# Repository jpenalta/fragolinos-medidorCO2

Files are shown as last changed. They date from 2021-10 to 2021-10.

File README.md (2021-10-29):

# fragolinos-medidorCO2
Medidor de CO2 para a aula realizado polo Club de Ciencias do IES Antonio Fraguas

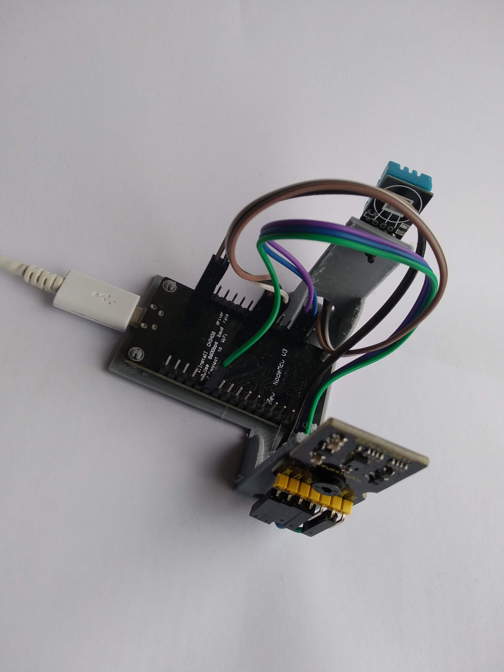
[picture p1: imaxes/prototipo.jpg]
prototipo


## Descrición do proxecto
Este dispositivo foi deseñado para ser montado polos alumnos do Club de Ciencias. Os obxectivos era por unha parte introducir aos alumnos no mundo IOT, e por outro dispoñer dun medidor da calidade do aire das aulas.

O sensor [CSS811](https://www.sciosense.com/products/environmental-sensors/ccs811-gas-sensor-solution/) utilizado non mide CO2, se non [VOC](https://es.wikipedia.org/wiki/Compuestos_org%C3%A1nicos_vol%C3%A1tiles), e realiza unha estimación do CO2 a partir desas medicións. Non é realmente o sensor ideal, xa que resulta moi sensible a compostos químicos, como productos de limpeza ou colonias, pero a relación calidade-precio era un requisito. Un sensor CCS811 pódese atopar entre 10 e 15 Euros, mentras que un sensor de maís calidade, que mide CO2 directamente, non baixa dos 30 Euros.

O precio do sensor de humidade e temperatura [DHT11](https://learn.adafruit.com/dht) é moi barato (2 Euros), por eso se aproveitou para engadilo, dando información adicional do estado da aula.

En total montáronse 20 dispositivos, que foron instalados en distintas aulas de 1º, 2º, 3º e 4º da ESO. En cada aula había un cartel cun código QR que permitía o acceso á páxina de [thingspeak.com](https://thingspeak.com/)  cos datos e gráficas dos parámetros recollidos.

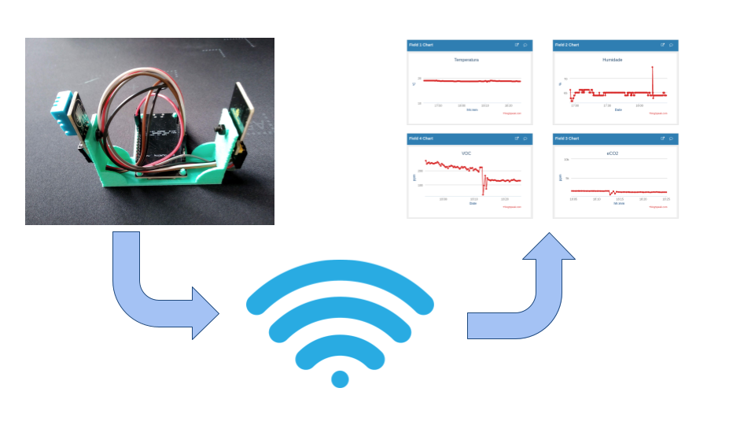
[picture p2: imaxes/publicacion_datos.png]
publicación de los datos


O coste de cada dispositivo foi aproximadamente duns 22 euros. Na carpeta docs existe unha folla de cálculo coa estimación dos costes de cada compoñente.
                                                       
## Carpetas
* **doc**: Presentacións realizadas para explicar aos alumnos o proxecto e como manuais de montaxe.
* **src**: Código arduino
* **soporteESP8266**: ficheiros para a impresión 3D do soporte da placa e os sensores.
* **imaxes**: Diversas imaxes do sensor e os seus compoñentes.

##

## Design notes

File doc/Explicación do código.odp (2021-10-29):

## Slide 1

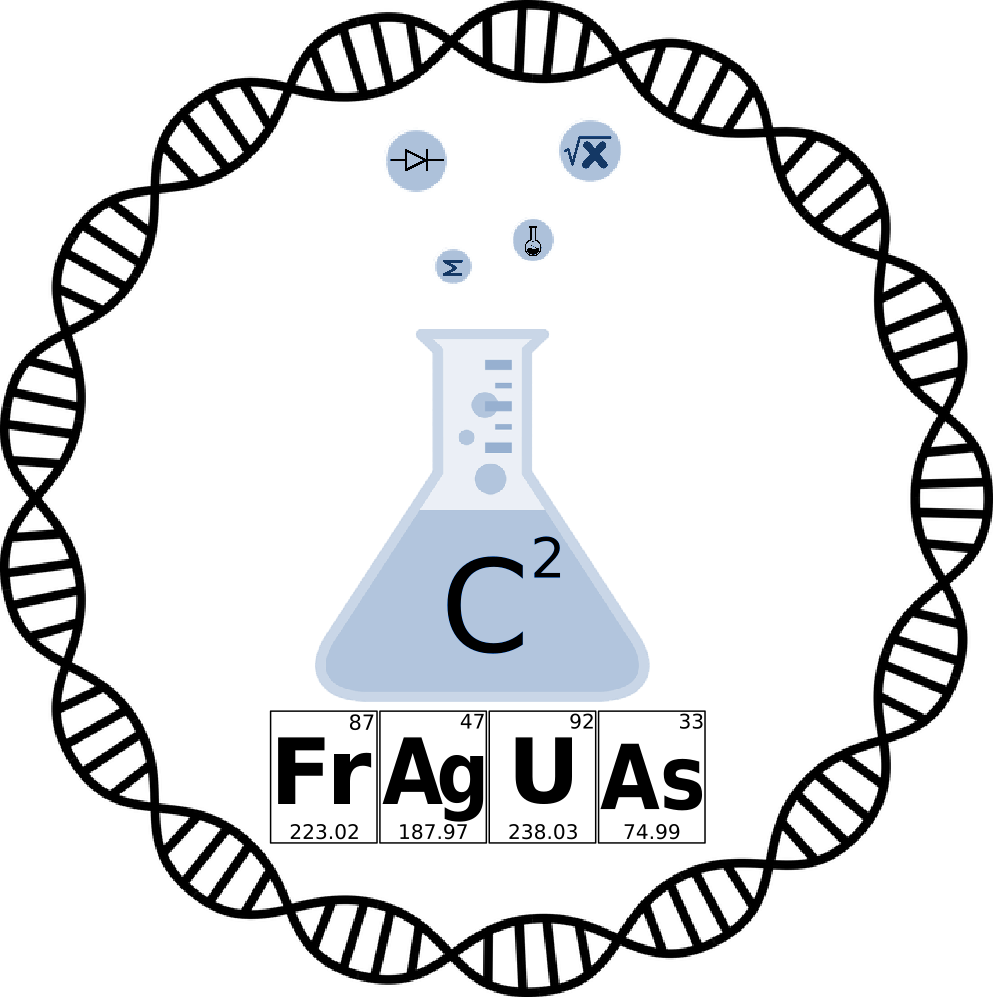
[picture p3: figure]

Explicación do código

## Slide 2

#include "secrets.h"

#include "ESP8266WiFi.h"

#include "ThingSpeak.h"

#include "DHT.h"

#include "Adafruit_CCS811.h"

Esta parte encárgase de cargar as librerías que nos van facilitar crear o programa.

As librerías son pequenos programas que fixo outra xente e que fan parte do traballo por nos. Así o noso programa é máis pequeno e maís fácil de entender

- ESP8266WiFi.h Permite conectarse a unha rede wifi.
- ThingSpeak.h Permite enviar os datos ao servidor de internet.
- DHT.h Permite leer os datos do sensor de temperatura.
- Adafrouit_CCS811.h Permite leer os datos do sensor de CO2.

Configuración 1

Cargar librerías

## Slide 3

// Configuración conexión a ThingSpeak

unsigned long myChannelNumber = SECRET_CH_ID;

const char * myWriteAPIKey = SECRET_WRITE_APIKEY;

const char * myReadAPIKey = SECRET_READ_APIKEY;

// Configuración conexión a WIFI

char ssid[] = SECRET_SSID;

char pass[] = SECRET_PASS;

// Pin donde ler os datos do sensor de DHT11

uint8_t DHTPin = DHT_PIN;

// Variables onde gardar os datos

float temperatura;

float humidade;

float eCO2;

float VOC;

// Liña base para o arrancar o sensor CCS811

uint16_t CCS811_baseline;

Adafruit_CCS811 ccs;

DHT dht(DHT_PIN, DHTTYPE);

WiFiClient client;

Esta parte encargase de definir e dar valores a variables que despois imos necesitar.

Damos valores por exemplo a wifi á que nos imos conectar e a súa contrasinal. E o pin onde hai que conectar o sensor de humidade.

Definimos variables onde imos gardar os datos de temperatura, humidade, etc...

Configuración 2

Definir variables

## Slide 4

Empezamos o bloque setup() que se executa só unha vez, cada vez que enchufamos a placa. Este bloque vale para arrancar todo o que imos necesitar despois.

O primeiro que facemos e conectarnos á WIFI.

Esta liña: while (WiFi.status() != WL_CONNECTED) {

Vai facer que o intente ata que consiga conectarse.

Se o consegue imprime polo porto serie ( se a placa está enchufada a un ordenador) a IP.

void setup() {

Serial.begin(9600);

delay(100);

// Conectado coa WIFI

WiFi.mode(WIFI_STA);

if (WiFi.status() != WL_CONNECTED) {

Serial.print("Intentando conectar a rede WIFI: ");

Serial.println(SECRET_SSID);

while (WiFi.status() != WL_CONNECTED) {

WiFi.begin(ssid, pass);

Serial.print(".");

delay(5000);

}

Serial.println("\nConnected.");

}

// Mostrar la dirección ESP IP en el Monitor Serie

Serial.println(WiFi.localIP());

Preparación 1

Conexión a wifi

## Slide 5

Nesta parte configuramos e probamos a conexión con ThinkSpeak, a páxina onde imos gardar os datos do nos sensor

// Iniciamos a conexión coa páxina onde enviar os datos

ThingSpeak.begin(client);

int statusCode = 999;

boolean existsBaseline = false ;

Serial.print("Intentando recuperar baseline para CCS811:");

for( int i=0; i<4; i++){

CCS811_baseline = ThingSpeak.readLongField(myChannelNumber, 5, myReadAPIKey);

statusCode = ThingSpeak.getLastReadStatus();

delay(5000);

Serial.print(i);

if(statusCode == 200){

existsBaseline = true;

break;

}

}

Serial.println(CCS811_baseline);

Preparación 2

Conexión a ThinkSpeak

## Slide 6

Nesta parte onde imos preparar o sensor de temperatura e de CO2.

//Iniciar sensor DHT11

Serial.println("Iniciando sensor temperatura");

pinMode(DHT_PIN, INPUT);

dht.begin();

//Iniciar sensor CSS811

Serial.println("Iniciando sensor CO2");

if(!ccs.begin()){

Serial.println("Error al iniciar el sensor de CO2.");

while(1);

}

ccs.setDriveMode(CCS811_DRIVE_MODE_10SEC);

if(existsBaseline){

ccs.setBaseline(CCS811_baseline);

}

// Esperamos a que todo esté listo.

delay(DELAY);

}

Preparación 3

Configuración sensores

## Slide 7

Leemos os datos dos sensores e os gardamos nas variables que xa tiñamos preparadas.

*

* Aquí leemos os valores dos sensores é o enviamos ao servidor.

*

*/

void loop() {

// Leemos a temperatura e humidade do sensor DHT11

temperatura = dht.readTemperature();

humidade = dht.readHumidity();

// Leemos o VOC e eCO2 do sensor CCS811

if(ccs.available()){

if(!ccs.readData()){

eCO2 = ccs.geteCO2();

VOC = ccs.getTVOC();

CCS811_baseline = ccs.getBaseline ();

ccs.setEnvironmentalData(temperatura, humidade);

}

}

Todo o rato...

Leemos os sensores

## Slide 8

Enviamos os datos que leimos dos sensores á páxina de ThingSpeak.

Tamén os enviamos ao USB (por serie) para poder comprobar dende un ordenador que funciona ben.

// Enviamos os datos ao servidor

ThingSpeak.setField(1,temperatura);

ThingSpeak.setField(2,humidade);

ThingSpeak.setField(3,eCO2);

ThingSpeak.setField(4,VOC);

ThingSpeak.setField(5,CCS811_baseline);

int httpCode = ThingSpeak.writeFields(myChannelNumber, myWriteAPIKey);

if (httpCode == 200) {

Serial.println("Enviados los datos correctamente.");

digitalWrite(LEDPin, LOW);

delay(500);

digitalWrite(LEDPin, HIGH);

}

else {

Serial.println("Problema al enviar los datos. HTTP error code " + String(httpCode));

}

Todo o rato...

Enviamos os datos á web

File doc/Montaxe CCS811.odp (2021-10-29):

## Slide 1

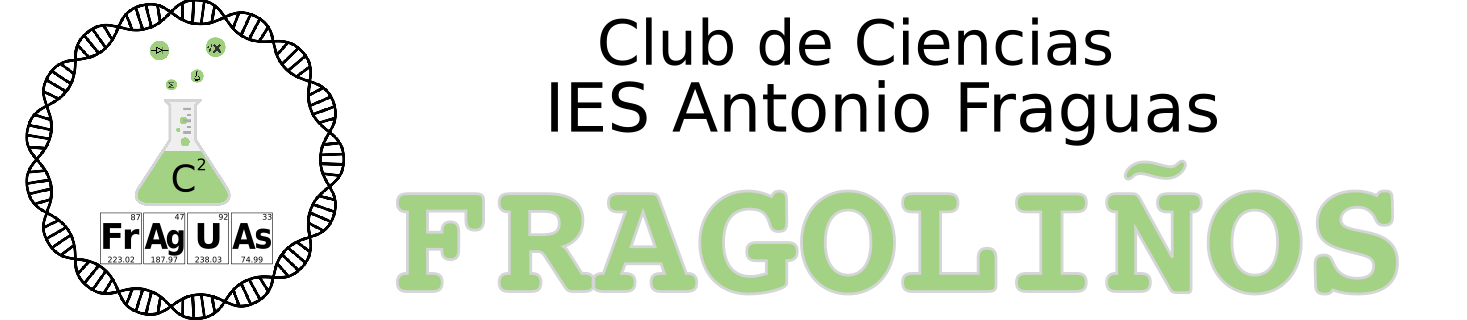
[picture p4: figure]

Montaxe sensor CO2

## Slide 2

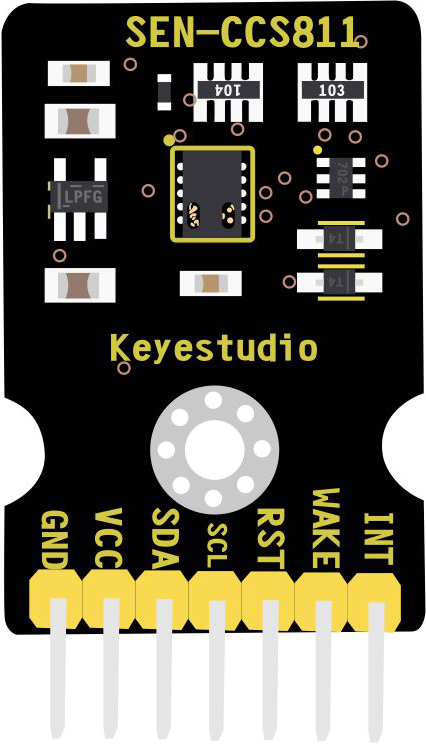
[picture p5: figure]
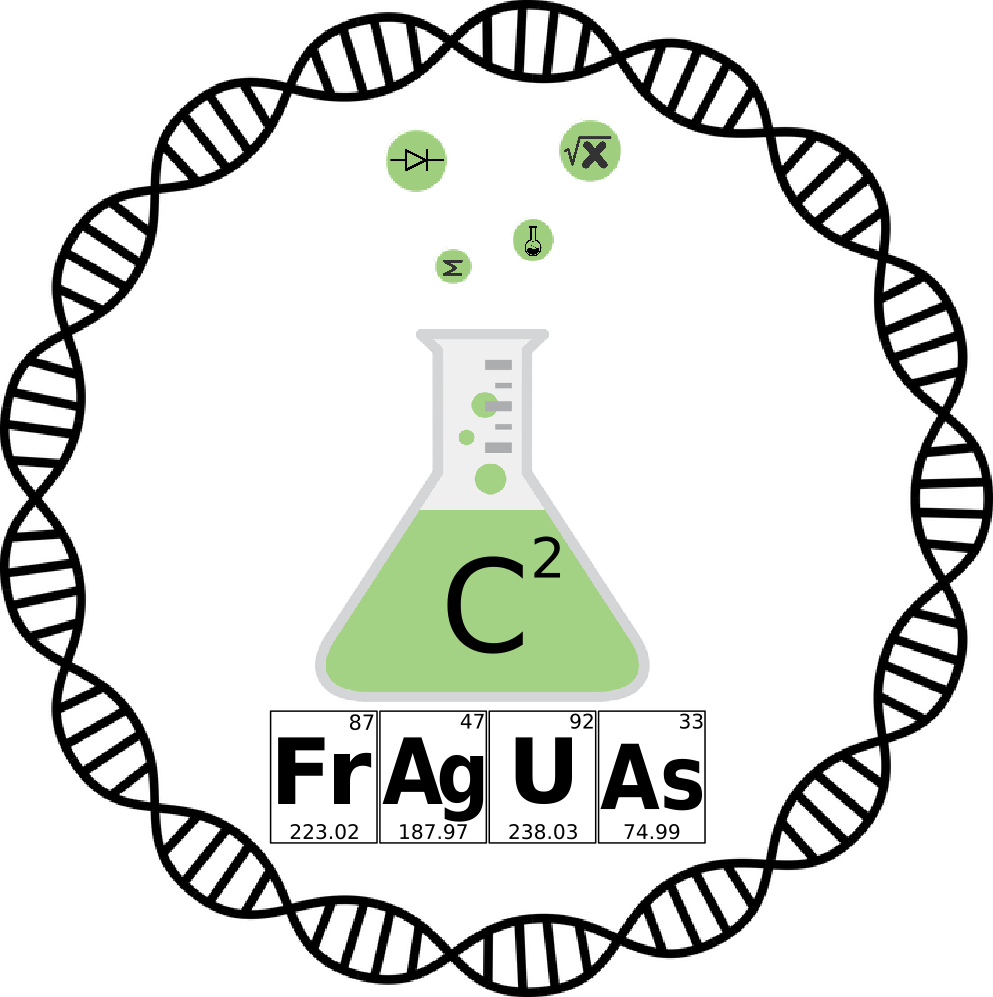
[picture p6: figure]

Modelo: CCS811

- Sensor de particulas VOC (Compuestos Organicos Volatiles)
- Estima particulas CO2 a partir das particulas VOC

CCS811 | Descripción
GND | Masa. Polo -
VCC | Voltaxe. Polo +
SDA | Datos para a transmisión das medicións
SCL | Datos para a transmisión das medicións
RST | Resetea o sensor
WAKE | Encende o sensor
INT | Indica cando o sensor ten unha nova medición.

Montaxe sensor CO2

Características e pines

CO2 1 de 2

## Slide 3

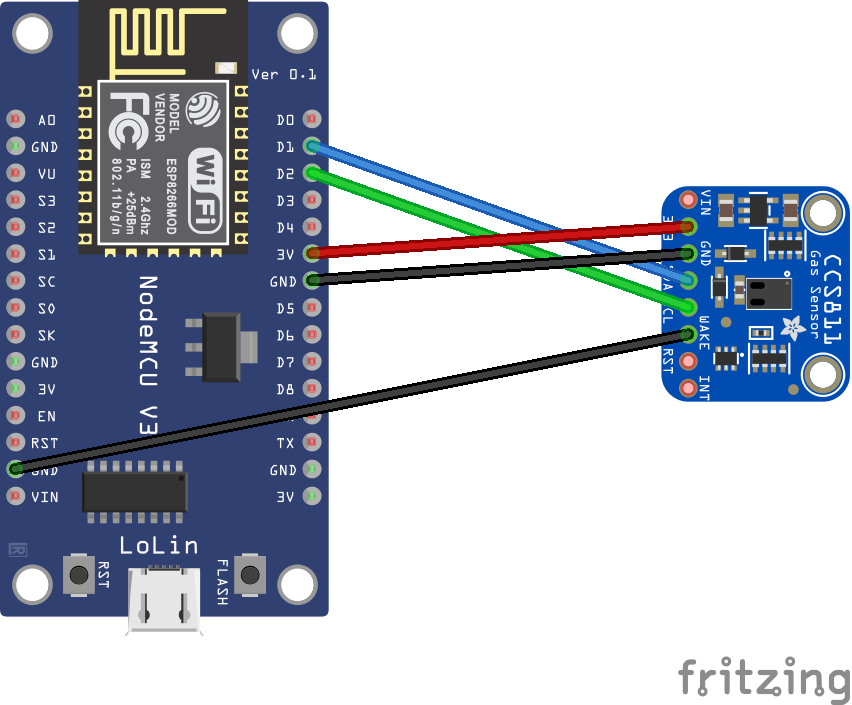
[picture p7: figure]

O gráfico corresponde a outro módelo. Fixarxe na táboa onde ten que ir cada cable na placa. Ter coidado sobre todo co VCC e o GND.

Montaxe sensor CO2

Como se enchufa á placa

CCS811 | PLACA
GND | GND
VCC | 3V
SDA | D1
SCL | D2
RST | -
WAKE | GND
INT | -

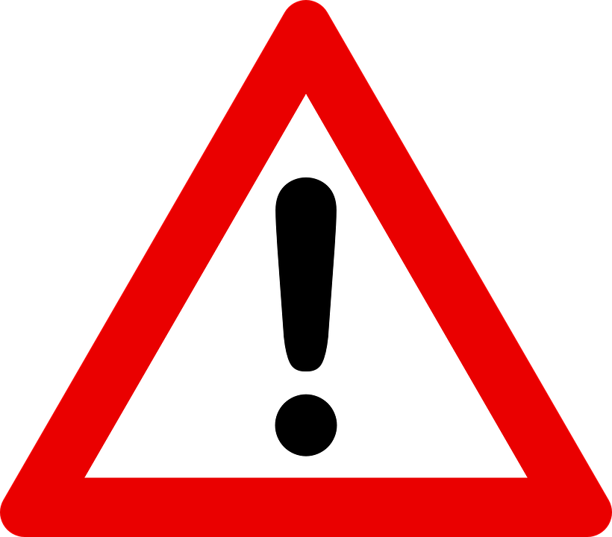
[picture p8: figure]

CO2 2 de 2

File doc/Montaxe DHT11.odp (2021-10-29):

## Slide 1


Montaxe sensor Temperatura e humidade

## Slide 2

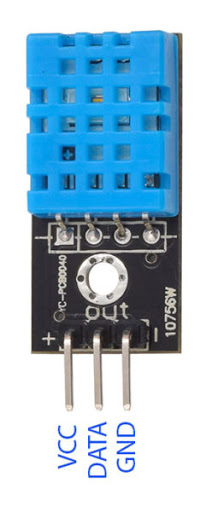
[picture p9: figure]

Modelo: DHT11

- Proporciona información da temperatura e da humidade no ambiente.
- A temperatura en ºC a humidade en %

DHT11 | Descrición
+ | Alimentación. Polo +
OUT | Datos
- | Masa. Polo -

Montaxe sensor Temp. e Hum.

Características e pines

DHT11 1 de 2

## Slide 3

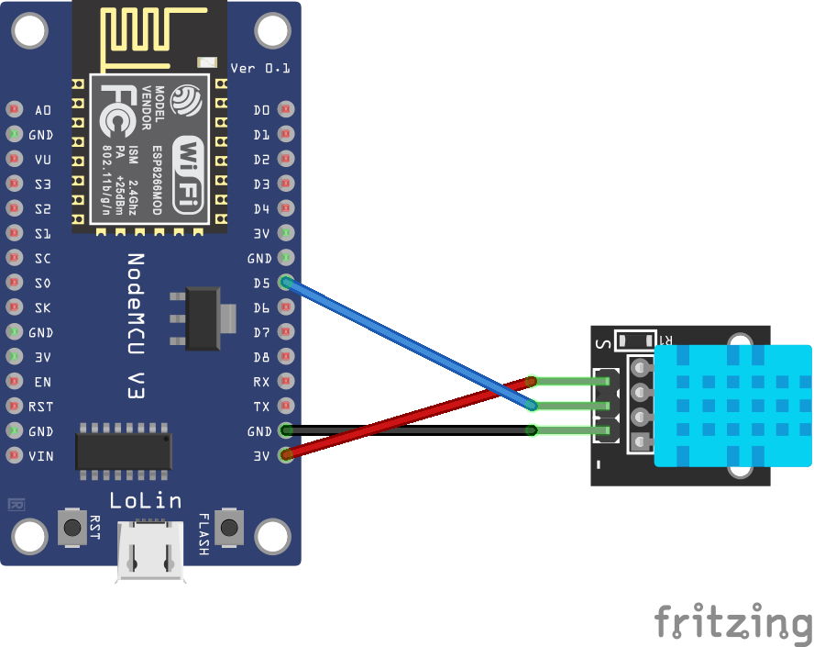
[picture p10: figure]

Fixarxe na táboa onde ten que ir cada cable na placa. Ter coidado sobre todo co + e o -, xa que enchufalos ao reves pode queimar o sensor.

Montaxe sensor Temp. e Hum.

Como se enchufa á placa

DHT11 | PLACA
+ | 3V
OUT | D5
- | GND


DHT11 2 de 2

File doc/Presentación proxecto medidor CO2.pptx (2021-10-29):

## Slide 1


Medidor de CO2

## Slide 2

Por qué medir o CO2?

A COVID é a ventilación

O Problema

En ambientes interiores, as partículas en suspensión, os aerosoles, que poden conter virus, pódense acumular.

A Solución

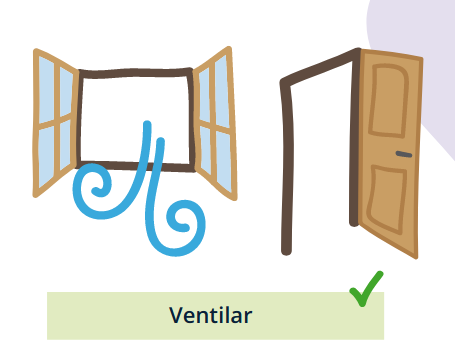
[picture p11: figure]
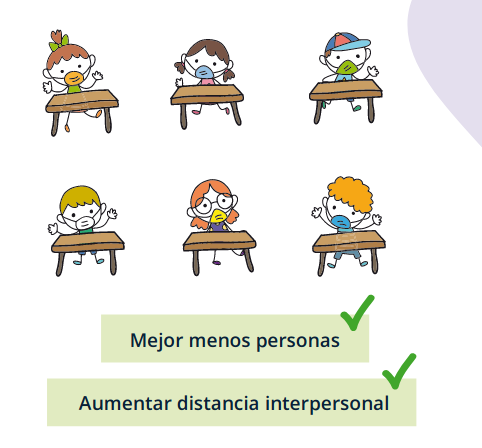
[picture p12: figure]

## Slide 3

No aire exterior as concentracións de CO2 son de 420 ppm.

Os seres humáns ao respirar expulsamos CO2

Se non hai ventilación o CO2 acumúlase e sube rápidamente

Por qué medir o CO2?

O CO2 e a ventilación

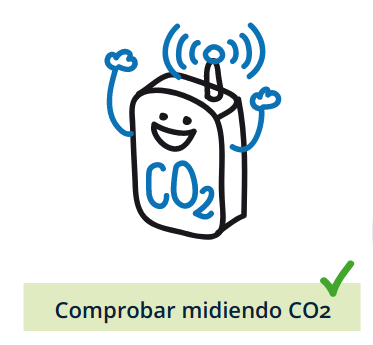
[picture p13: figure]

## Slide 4

Fonte CSIC: para aula de 61 m³ con 21 alumnos e 1 docente

Por qué medir o CO2?

Un exemplo

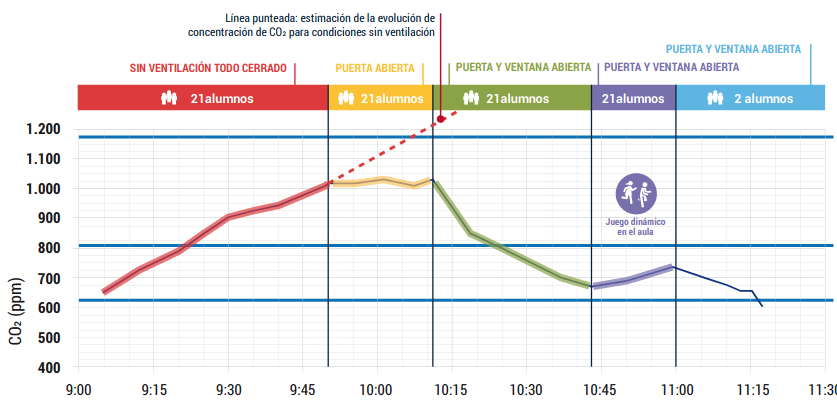
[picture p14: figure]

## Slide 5

Canto menos CO2 teñamos nunha aula é que mellor estamos a ventilar e por tanto que menos particulas que poden ter virus.

Por qué medir o CO2?

En resumen

Mellor ventilación

Menos CO2 no aire

Menos COVID no aire

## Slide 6

Como o imos facer?

Opcións

Comprar

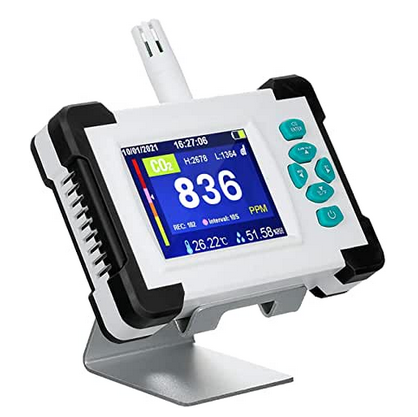
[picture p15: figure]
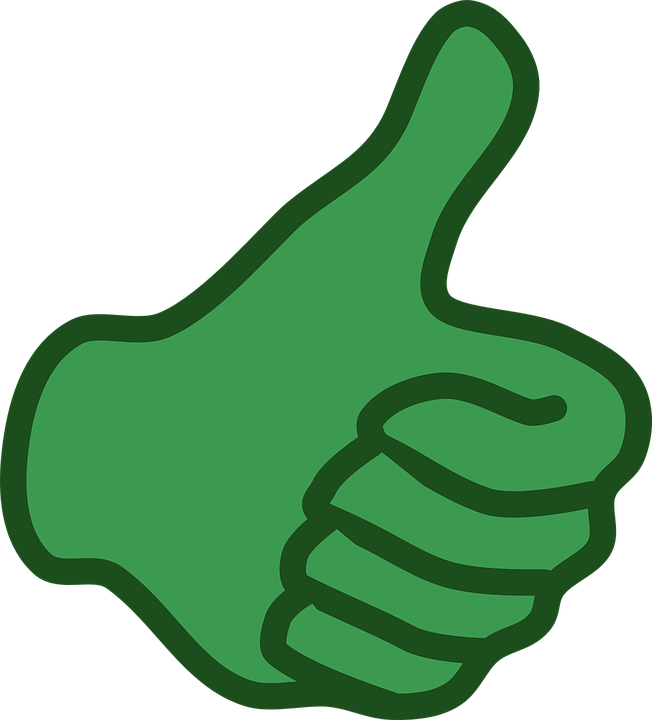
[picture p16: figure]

Fácil de poñer a funcionar. Preciso

Facelo

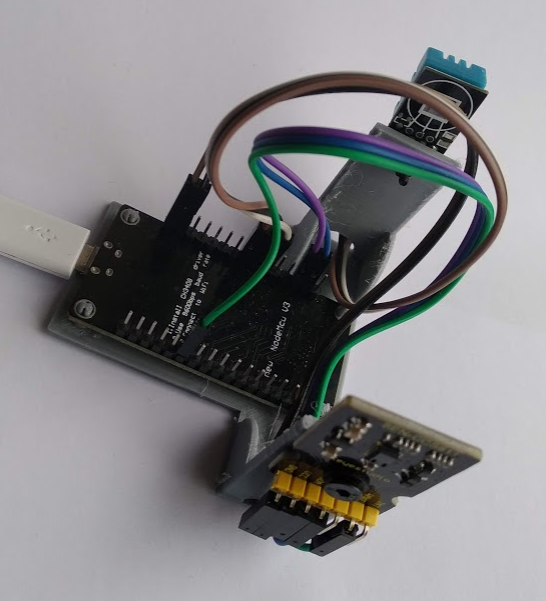
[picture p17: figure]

Barato. Configurable e ampliable.

Hai que montalo un mesmo. Complicado. Menos preciso

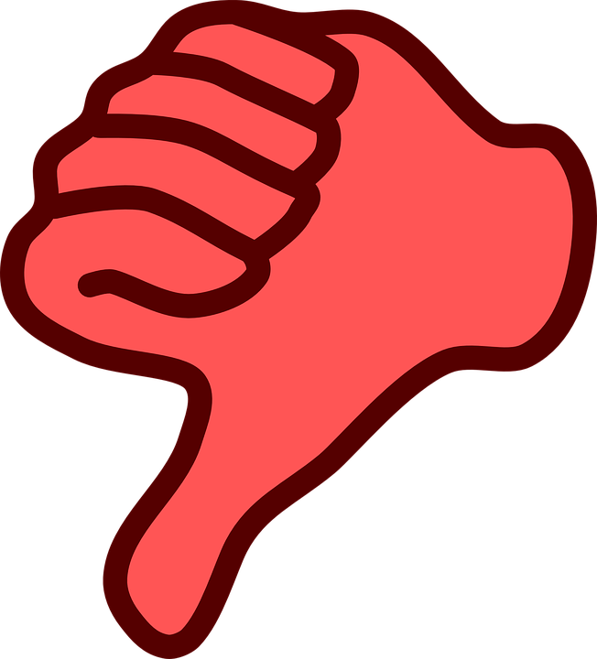
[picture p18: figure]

Caro. Non ampliable.

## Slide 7

Como o imos facer?

Sensor de vCO2

- Non mide realmente CO2 se non VOC (Compuestos Organicos Volatiles) e estima o CO2 a partir deles.
- É barato con respecto a outros sensores de CO2
- Non da medidas tan precisas como outros pero si o suficiente para as necesidades da nosa práctica.


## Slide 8

- Mide a temperatura e a humidade do hambiente
- Complementa a información das medicións de CO2.
- Axuda ao sensor de CO2 a ter medidas máis precisas.

Como o imos facer?

Sensor de temperatura e humidade

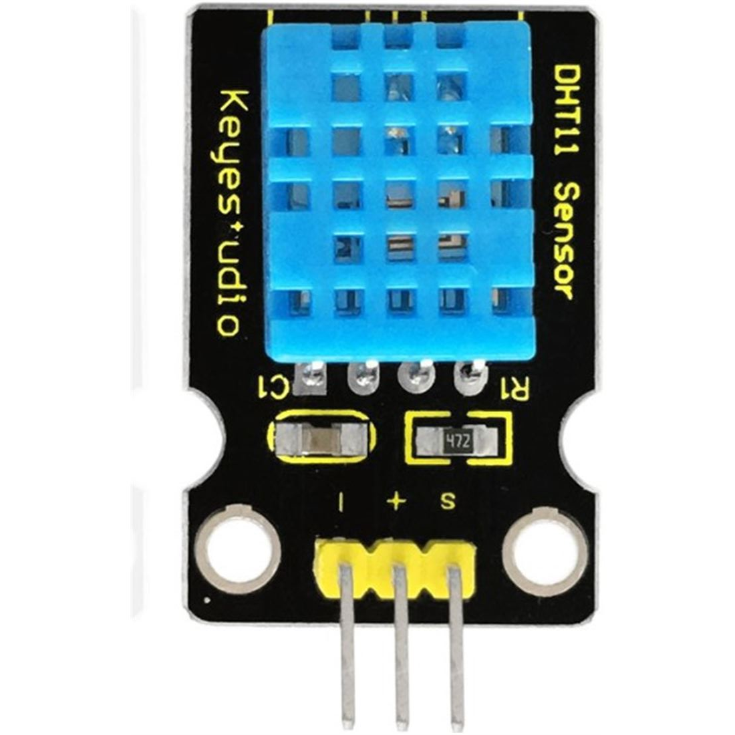
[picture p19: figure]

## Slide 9

- Placa microcontroladora programable con arduino.
- Ten posibilidade de conexión por WIFI
- Moi potente para o pouco que custa.

Como o imos facer?

Placa microcontroladora con WIFI

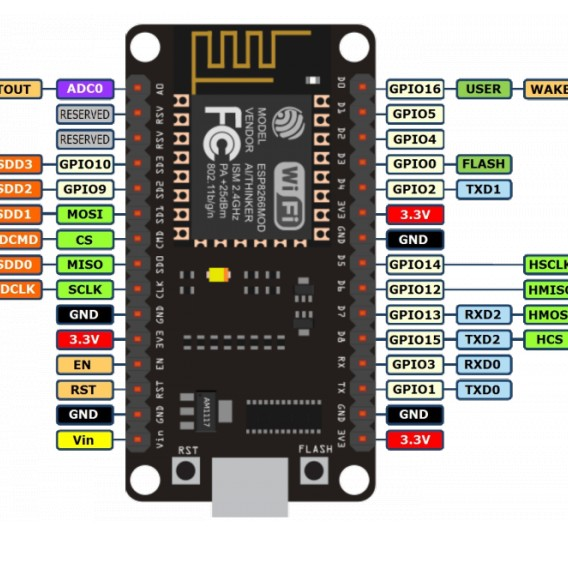
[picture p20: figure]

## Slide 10

Como o imos facer?

Os datos na nube

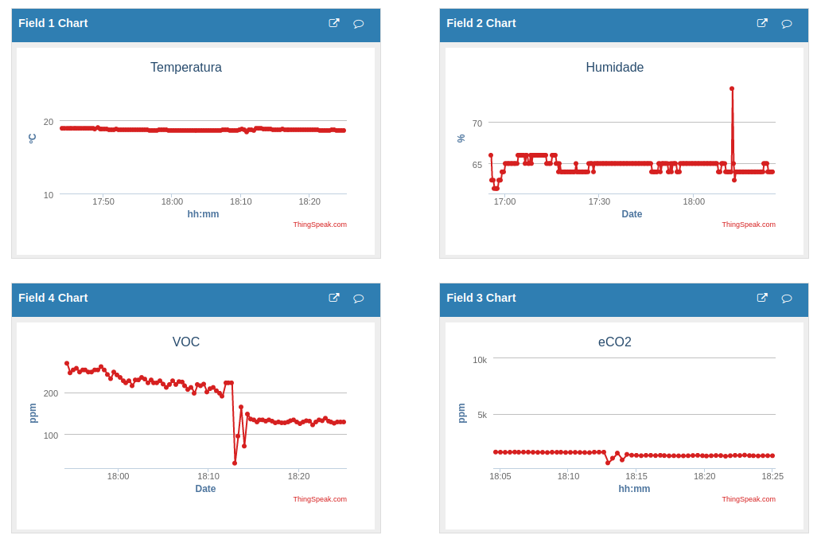
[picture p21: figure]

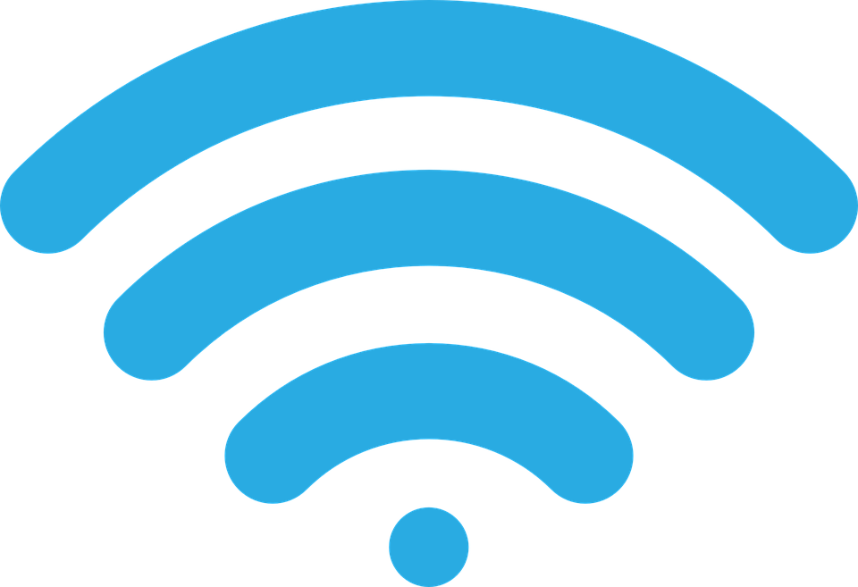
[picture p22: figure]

Internet

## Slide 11

Organización

Equipos de 4

Equipo formado por 4 alumnos e un profesor

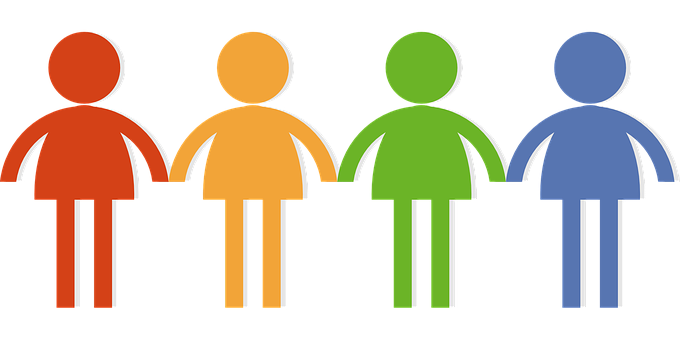
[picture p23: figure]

Cada vai recibir:

1 x Sensor de CO2

1 x Sensor de temperatura e humidade

1 x placa microcontroladora

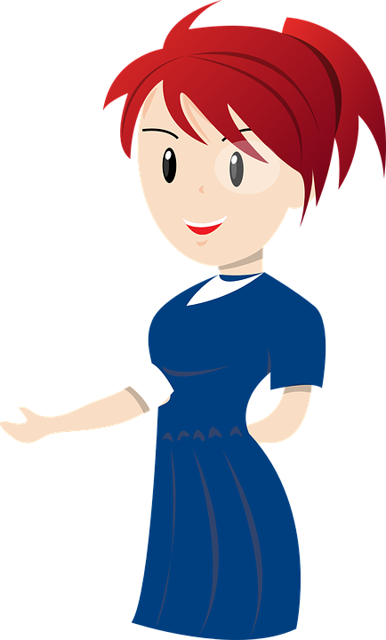
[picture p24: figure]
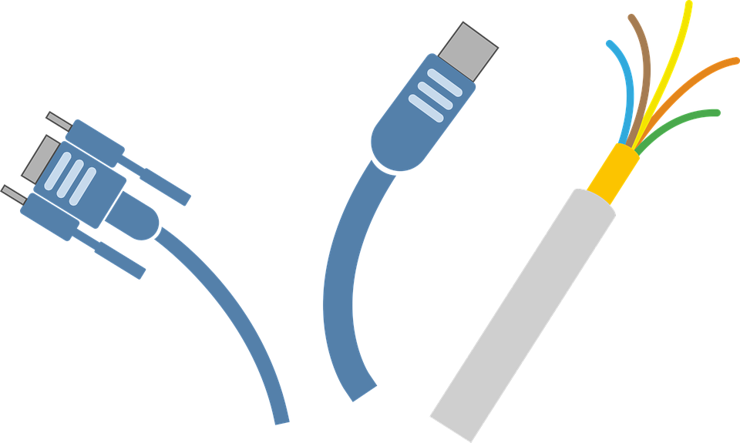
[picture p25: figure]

Un montón de cables.

1 x instruccións de como montar todo.

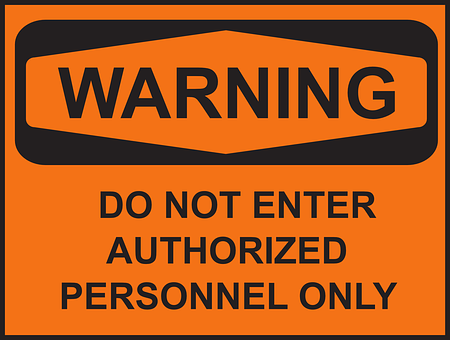
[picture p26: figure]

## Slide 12

Organización

Cada un na súa aula


Unha vez rematado e configurado cada equipo poñerá a funcionar o sensor na súa aula.

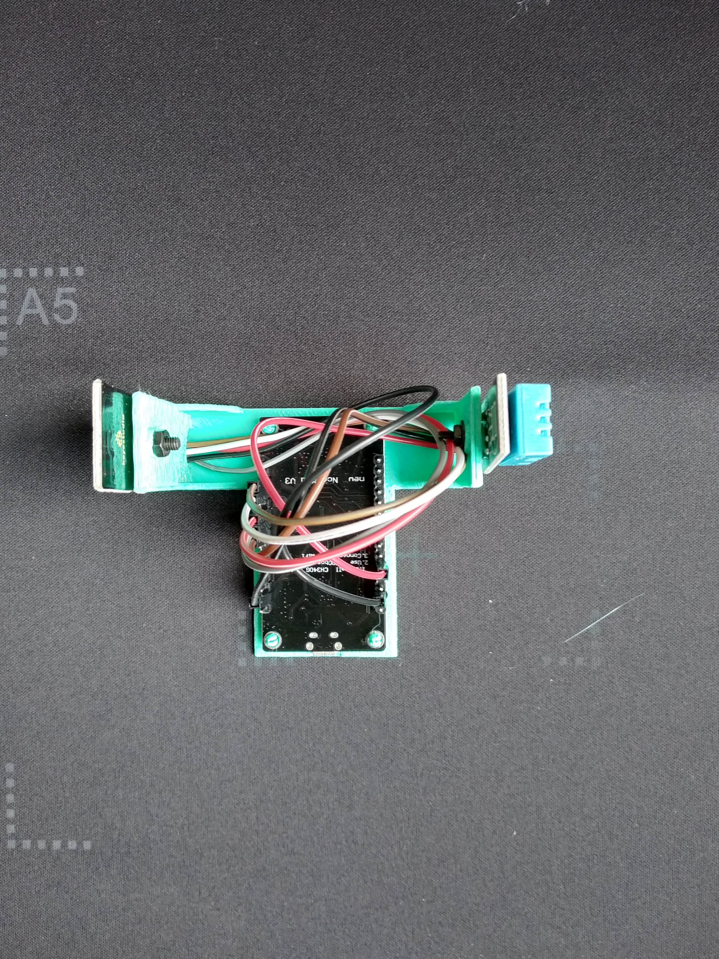
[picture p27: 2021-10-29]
imaxes/montado_vista_superior.jpg

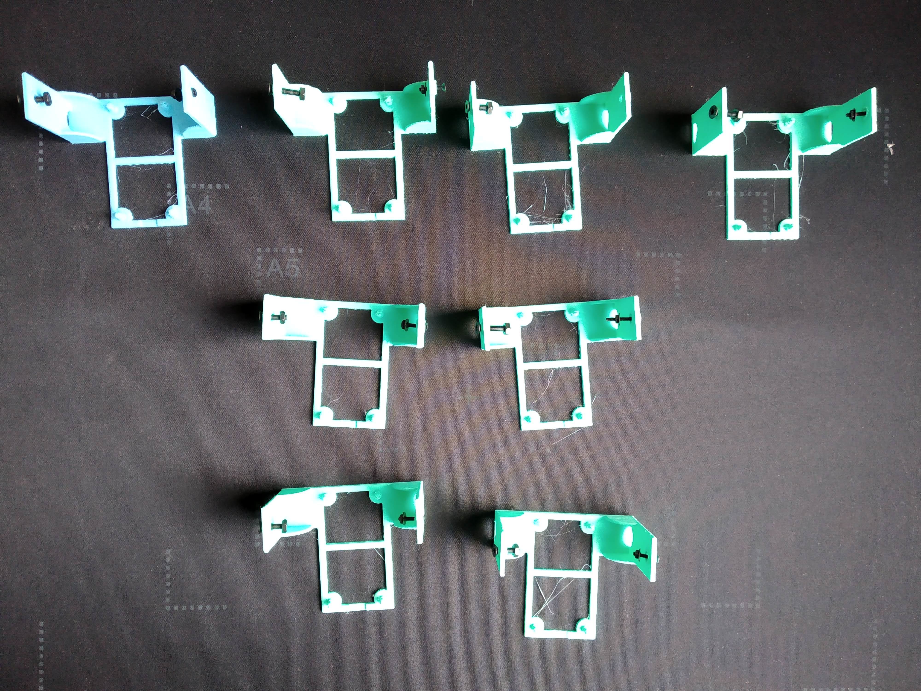
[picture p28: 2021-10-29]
imaxes/soportes_3.jpg

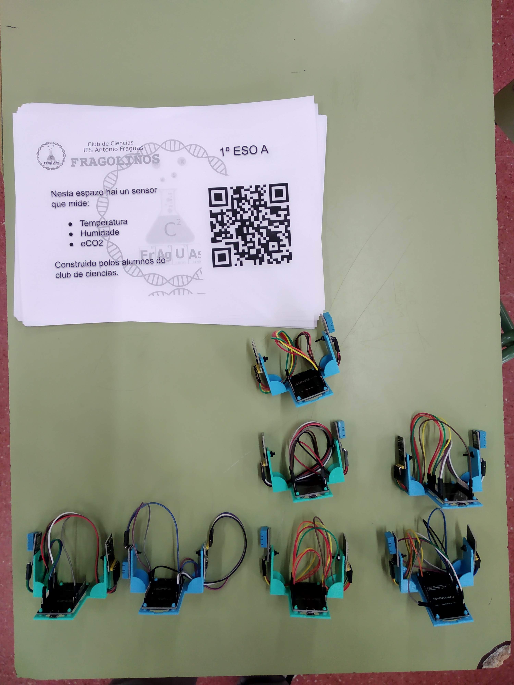
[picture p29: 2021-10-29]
imaxes/preparados_para_a_aula_1.jpg

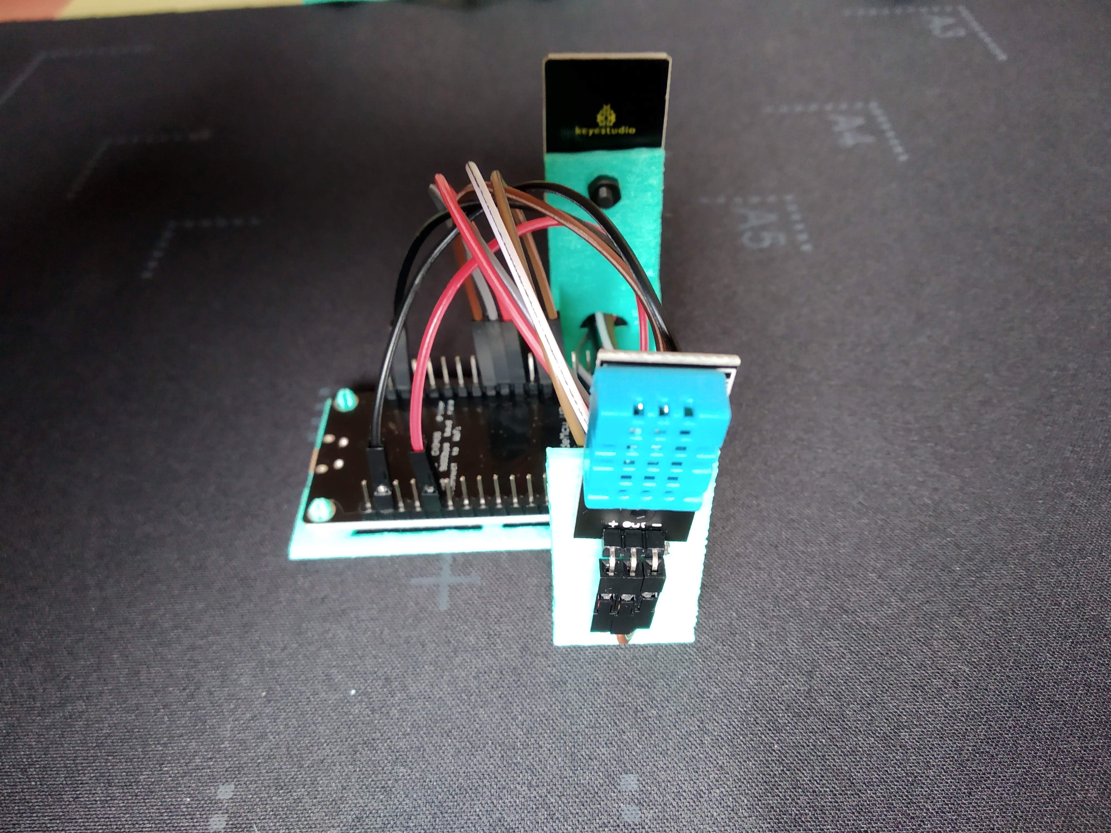
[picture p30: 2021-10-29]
imaxes/montado_vista_lateral_sensor_H.jpg

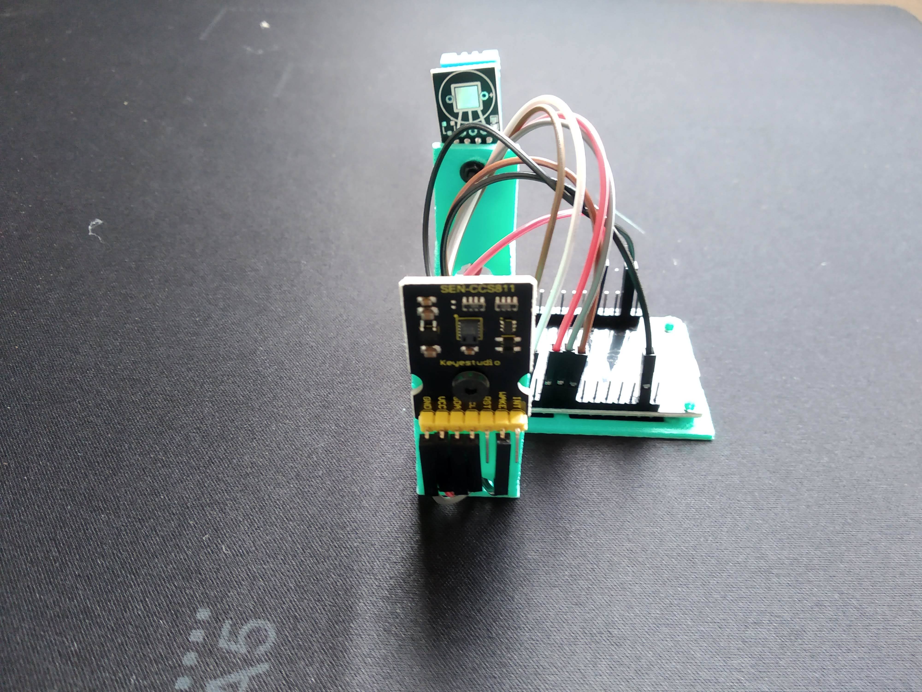
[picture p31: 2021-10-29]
imaxes/montado_vista_lateral_sensorCO2.jpg

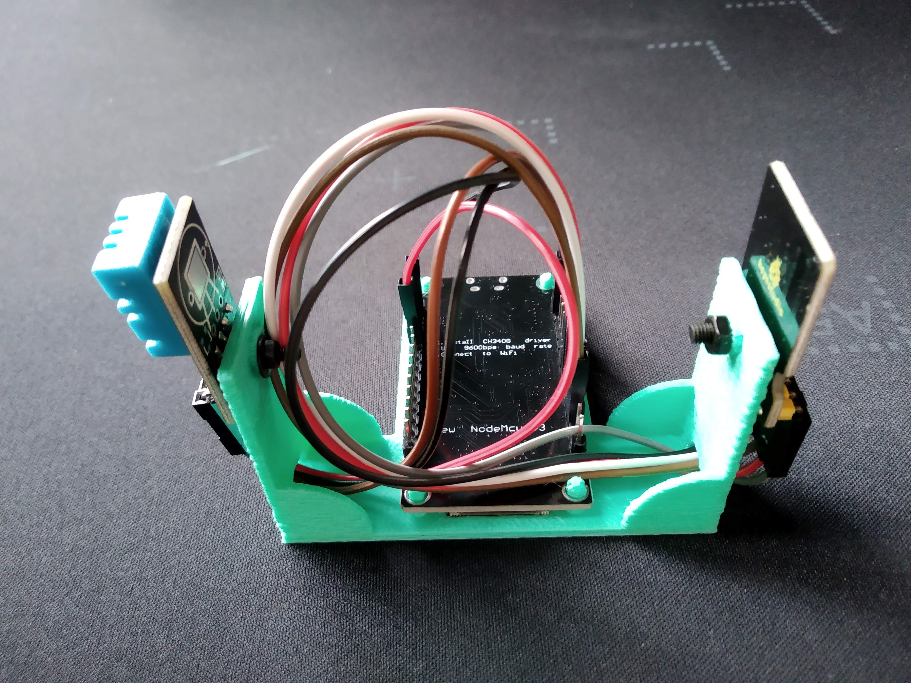
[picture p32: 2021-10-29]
imaxes/montado_vista_frontal.jpg

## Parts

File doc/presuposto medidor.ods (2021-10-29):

Material | Precio | amazon | Precio | AliExpress | Precio | Bricogeek
ESP8266 NodeMCU Lolin V3 | 4.4 | https://www.amazon.es/dp/B074Q27ZBQ | 1.9 | https://es.aliexpress.com/item/4000055280006.html | 4.1 | https://tienda.bricogeek.com/wifi/1033-nodemcu-v3-wifi-esp8266-ch340.html?search_query=esp8266&results=22
Sensor CO2: CCS811 | 13.99 | https://www.amazon.es/KEYESTUDIO-Quality-Arduino-Monoxide-Numeric/dp/B08GP947QS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 | 9.1 | https://es.aliexpress.com/item/4000073907942.html | 19.95 | https://tienda.bricogeek.com/sensores-gas/1508-sensor-de-calidad-del-aire-ccs811-voc-y-co2.html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
Sensor Temp e Humid.: DHT11 | 2.2 | https://www.amazon.es/WINGONEER-humedad-temperatura-frambuesa-Arduino/dp/B06XHJ1BPC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 | 0.54 | https://es.aliexpress.com/item/1005001621864387.html | 1.3 | https://tienda.bricogeek.com/sensores-temperatura/986-sensor-de-humedad-y-temperatura-dht11.html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
Cableado | 0.7 | https://www.amazon.es/SODIAL-Puente-Hembra-Soldadura-Flexible/dp/B00HUH9GOC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 | 0.2 |  | 0.2 | https://tienda.bricogeek.com/cables/1363-cables-dupont-hembra-hembra-20-cm-40-unidades.html
Fuente alimentacion | 0
Precio por unidad | 21.29 |  | 11.74 |  | 25.55
20 | 425.8 |  | 234.8 |  | 511
25 unidades CCS811 a 3,6 | https://www.amazon.es/dp/B074Q2WW1X

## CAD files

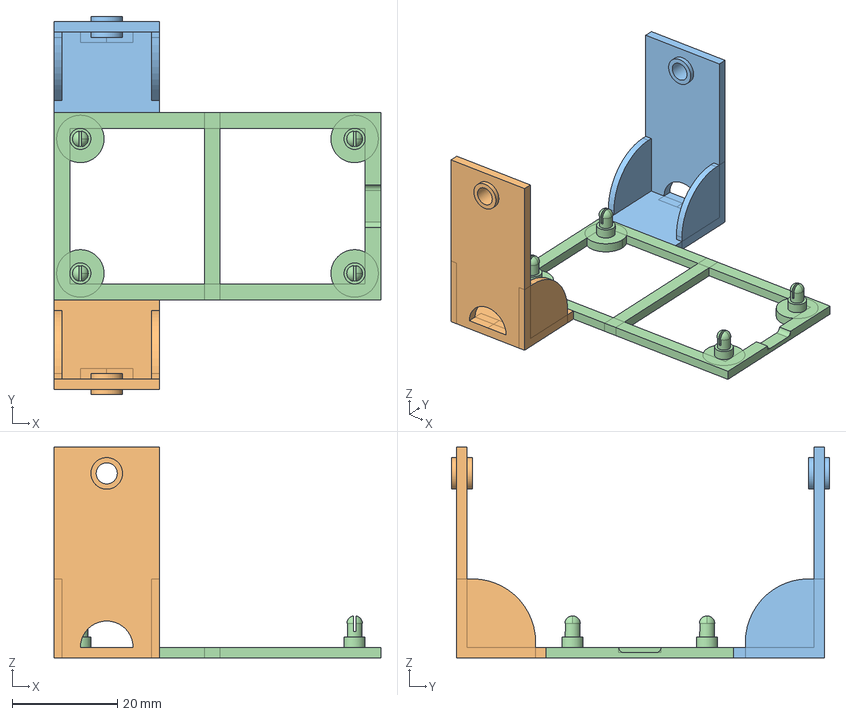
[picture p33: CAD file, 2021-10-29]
soporteESP8266/Caixa ESP8266 V2.FCStd
62.0 x 71.8 x 40.0 mm
Soporte sensor
Soporte sensor001
Soporte sensor001 (Mirror #1)
Base ESP8266 con rebaje USB

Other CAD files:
soporteESP8266/Caixa ESP8266 V2.stl

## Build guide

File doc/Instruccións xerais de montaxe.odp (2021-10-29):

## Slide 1


Instrucións para a montaxe do medidor de CO2

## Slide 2

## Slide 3


1 x Sensor de CO2

1 x Sensor de temperatura e humidade

1 x Placa microcontroladora

Montaxe 1

Cada equipo recibe

Un soporte onde montar todo

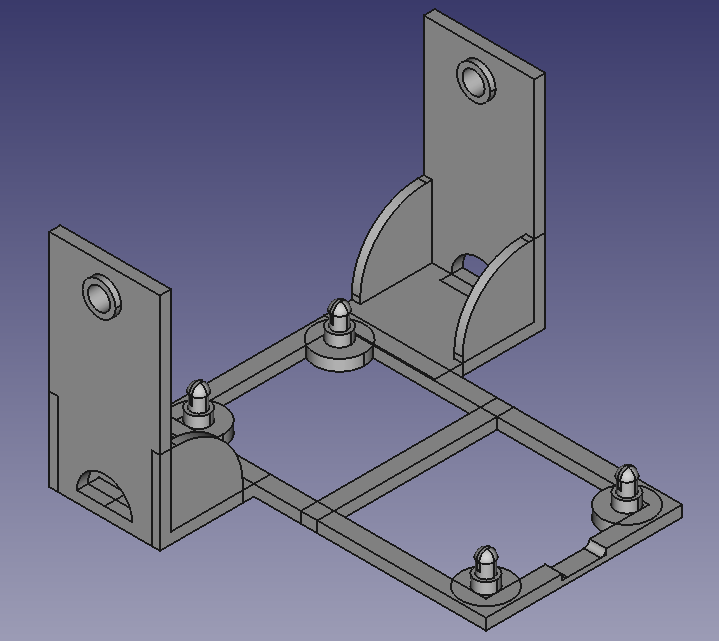
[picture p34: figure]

Un montón de cables.

1 x Instrucións de como montar todo.

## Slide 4

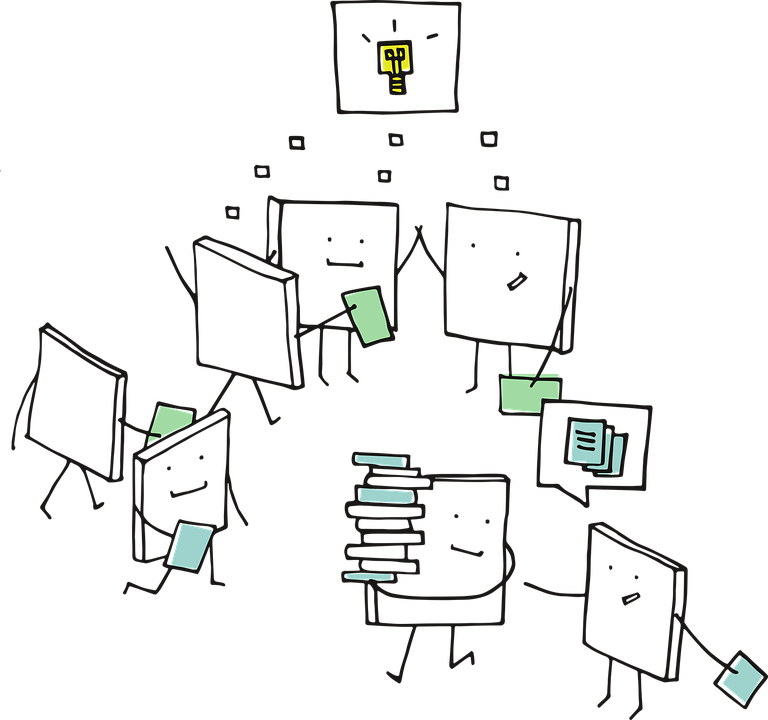
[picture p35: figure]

- Realizarase a montaxe durante os recreos que se desexen.
- Debe estar presente o profesor encargado do grupo.
- Unha vez rematada a montaxe hai que cargar o programa na placa.
- Non se debe enchufar a placa antes de que o programa esté cargado.

Montaxe 2

Cada un na súa aula fai

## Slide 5

1. Fíxase a placa controladora no centro do soporte, cos pins para arriba
2. Fíxanse os sensores ás alas do soporte. Cuns tornillos.
3. Enchúfanse os cables nos sensores e pásanse polo furado que ten cada ala.
4. Mirando os manuais de cada sensor enchúfanse os cables na placa.

Montaxe 3

Fixándose no modelo

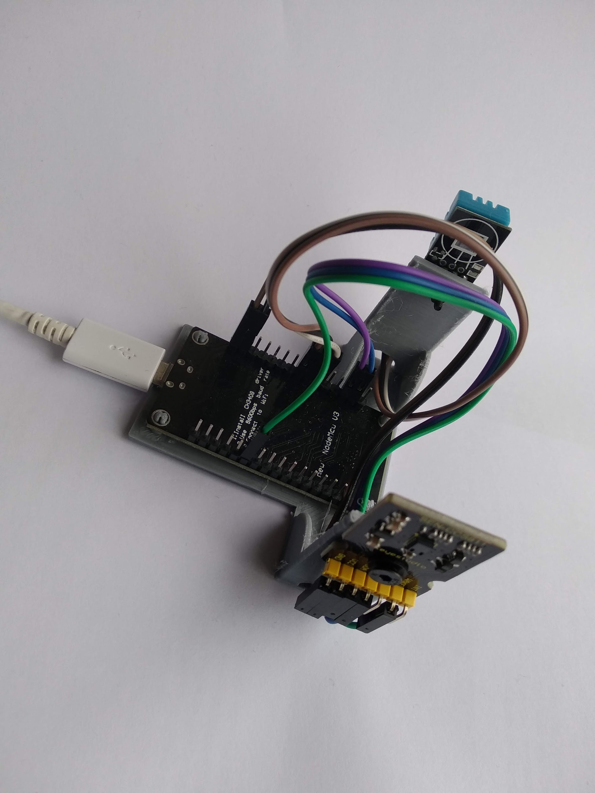
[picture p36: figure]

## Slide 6

Montaxe 4

Cargamos o programa.


Cárgase o programa, distinto para cada grupo, xa que ten que levar o código do panel onde se van a enviar os datos en internet.


Internet

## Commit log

2021-10-29 Primeira subida
    [Caixa ESP8266 V2.FCStd, Caixa ESP8266 V2.stl]
2021-10-29 Engadido presuposto
    [presuposto medidor.ods]
2021-10-29 Imaxe do proceso de publicación dos datos
